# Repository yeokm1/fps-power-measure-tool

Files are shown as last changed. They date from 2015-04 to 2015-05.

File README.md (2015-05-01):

# fps-power-measure-tool
An Arduino setup to measure the frames per second (FPS) and power usage of a connected Android device. If you just want to measure the power usage, you can check out this [previous project](https://github.com/yeokm1/power_measure_tool) of mine. FPS data is obtained via ADB over the USB cable and power via a current sensor.

I created this tool for the purposes of my final year project (FYP) and I have open-sourced it in case anyone wishes to learn from this setup.

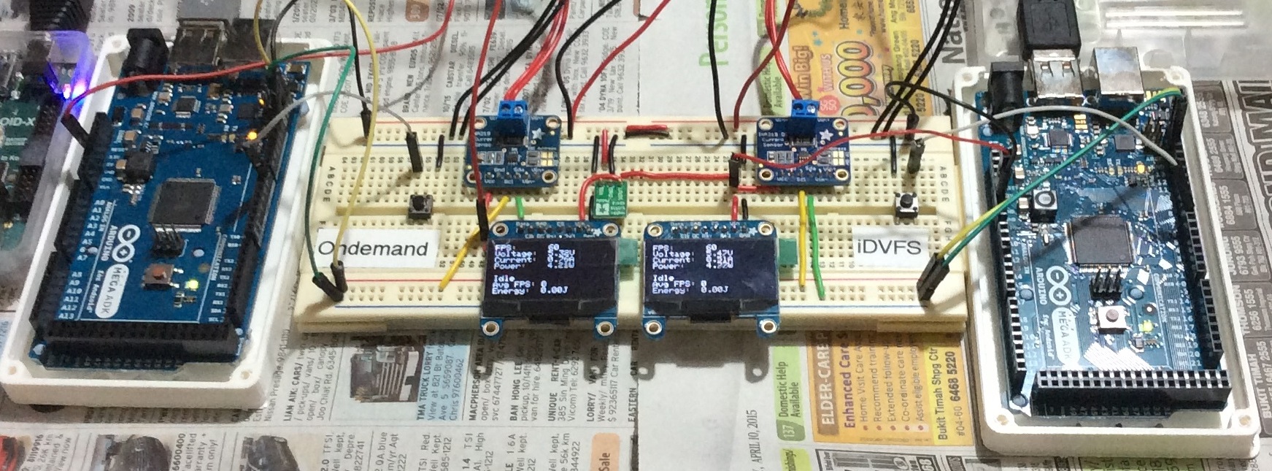
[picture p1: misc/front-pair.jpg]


Picture of two sets as used in my final year project.

###Video of my usage in my FYP
(https://www.youtube.com/watch?v=W7nGmd0tQ70)

###Schematic:

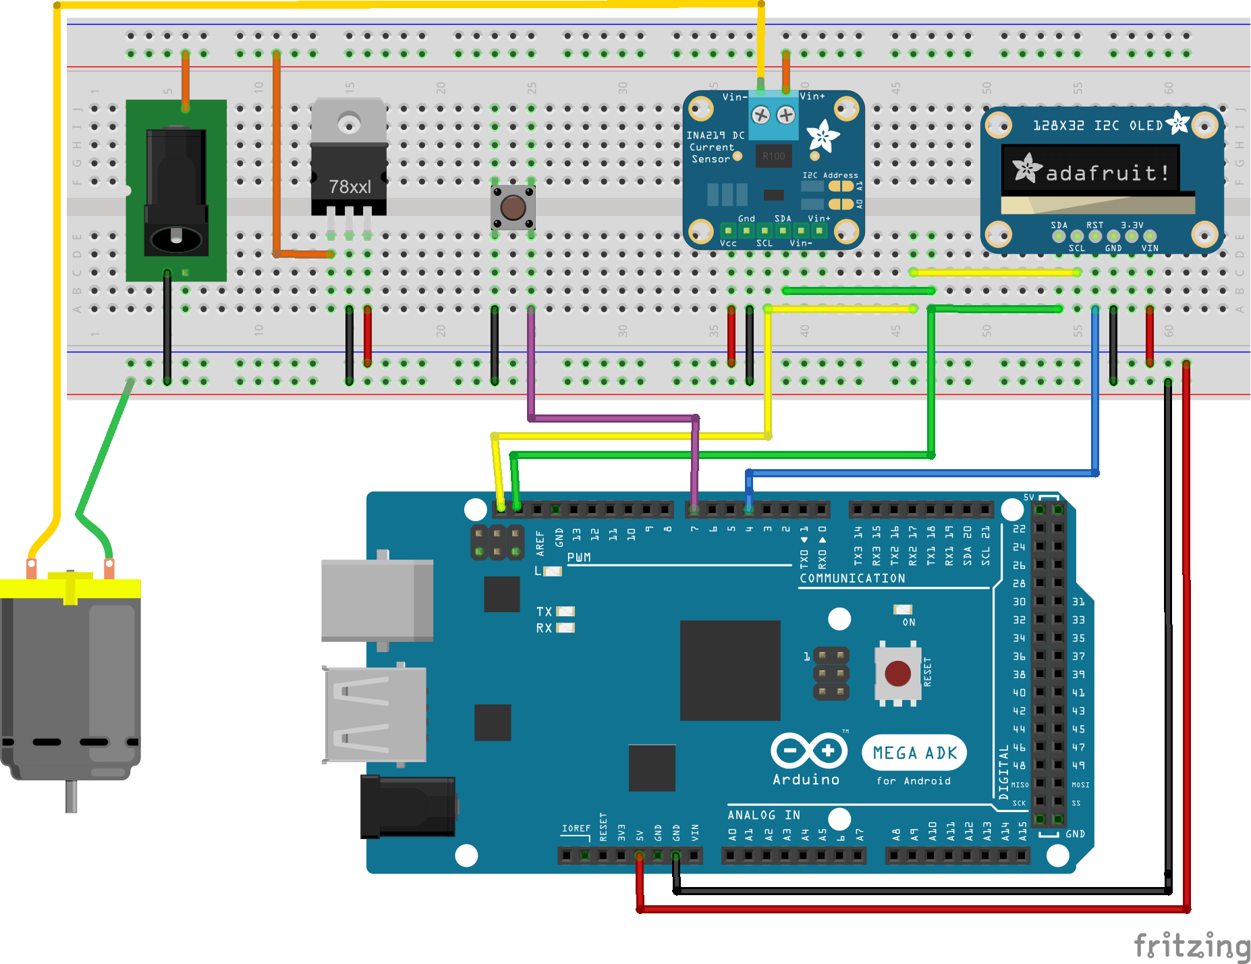
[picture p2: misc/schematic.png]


This logical schematic differs slightly from the physical curcuit layout. The motor here represents the phone. The barrel jack is the source supply power for both the motor and and the phone. The 78xxl represents any 5V voltage regulator you can use to supply 5V to the Arduino and the rest of the system in case your source voltage is very high.

##Parts List:
1. Arduino Mega ADK
2. Adafruit INA219 High Side DC Current Sensor Breakout
3. Adafruit 1.3" 128x64 OLED set to I2C
4. [Pololu 5V Step-Up/Step-Down Voltage Regulator S7V7F5](https://www.pololu.com/product/2119) (others will work fine)
5. Push Button

##References and libraries
1. [Smoothing algorithm](http://arduino.cc/en/Tutorial/Smoothing)
2. [Modified microbridge arduino](https://github.com/agoransson/microbridge-arduino)
3. [Standard C++ for Arduino](https://github.com/maniacbug/StandardCplusplus)

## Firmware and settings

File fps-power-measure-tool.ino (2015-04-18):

#include <Wire.h>
#include <SPI.h>
#include <Adb.h>
#include <StandardCplusplus.h>
#include <Stack>
#include <Adafruit_INA219.h>
#include <Adafruit_GFX.h>
#include <Adafruit_SSD1306.h>

using namespace std;

#define FPS_COMMAND "dumpsys SurfaceFlinger --latency SurfaceView && echo $\n"
#define FPS_RESULT_LINE_LENGTH 100
#define TIME_INTERVAL_FPS_SECOND 1000
#define TIME_SHELL_COMMAND_ISSUE 1000

#define MAX_FPS 60
#define NO_FPS_CALCULATED -1

#define POLL_RATE 500
#define SCREEN_RESET_PIN 4 //Digital 4
#define DISPLAY_CONTRAST true
#define PAST_POWER_TO_AVERAGE 10

#define MEASUREMENT_RATE 1000

#define PIN_BUTTON 7
#define DEBOUNCE_TIME 200

Adafruit_INA219 ina219;
Adafruit_SSD1306 display(SCREEN_RESET_PIN);

//Smoothing algorithm http://arduino.cc/en/Tutorial/Smoothing
float powerValues[PAST_POWER_TO_AVERAGE];      // the readings from the analog input
int powerValuesIndex = 0;                  // the index of the current reading
float powerValuesTotal = 0;                  // the running total
float powerValuesAverage = 0;                // the average

bool isMeasuring = false;

long lastPressedTime = millis();

double totalEnergyUsed = 0;
long totalFPSMeasured = 0;
int measurementsTaken = 0;
long timeLastMeasurementTaken = millis();

Connection * shell;

long shellLastCallTime = millis();

char resultLine[FPS_RESULT_LINE_LENGTH];
int currentLetter = 0;
stack<long> lastValues;
bool didPreviousFPSCommandSucceed = false;

int currentFPS = 0;

void setup() {
  Serial.begin(115200);
  ina219.begin();

  pinMode(PIN_BUTTON, INPUT_PULLUP);

  // Initialise the ADB subsystem.
  ADB::init();
  // Open an ADB stream to the phone's shell. Auto-reconnect
  shell = ADB::addConnection("shell:", true, adbEventHandler);

  // initialize with the OLED with I2C addr 0x3D (for the 128x64)
  display.begin(SSD1306_SWITCHCAPVCC, 0x3D);

  display.dim(DISPLAY_CONTRAST);

  display.clearDisplay();
  display.setTextColor(WHITE);
  display.setTextSize(1);
  display.setCursor(0, 0);
  display.display();

}

void loop() {
  float outputVolt = ina219.getBusVoltage_V();
  float outputAmp = ina219.getCurrent_mA() / 1000;

  float outputWattRaw = outputVolt * outputAmp;


  powerValuesTotal = powerValuesTotal - powerValues[powerValuesIndex];
  powerValues[powerValuesIndex] = outputWattRaw;
  powerValuesTotal = powerValuesTotal + powerValues[powerValuesIndex];
  powerValuesIndex++;

  // if we're at the end of the array...
  if (powerValuesIndex >= PAST_POWER_TO_AVERAGE) {
    powerValuesIndex = 0;
  }

  powerValuesAverage = powerValuesTotal / PAST_POWER_TO_AVERAGE;


  long currentTime = millis();
  // Poll the ADB subsystem.
  if (shell->status == ADB_OPEN) {


    if ((currentTime - shellLastCallTime) > TIME_SHELL_COMMAND_ISSUE) {
      shellLastCallTime = currentTime;
      ADB::writeString(shell, FPS_COMMAND);
    }
  }

  ADB::poll();


  int buttonStatus = digitalRead(PIN_BUTTON);

  if (buttonStatus == LOW && ((currentTime - lastPressedTime) > DEBOUNCE_TIME)) {
    lastPressedTime = currentTime;

    if (isMeasuring) {
      isMeasuring = false;
    } else {
      isMeasuring = true;

      measurementsTaken = 0;;
      totalEnergyUsed = 0;
      totalFPSMeasured = 0;
    }



  }



  if (isMeasuring) {
    if ((currentTime - timeLastMeasurementTaken) > MEASUREMENT_RATE) {

      if (currentFPS != NO_FPS_CALCULATED) {
        timeLastMeasurementTaken = currentTime;

        measurementsTaken++;
        totalEnergyUsed += powerValuesAverage;
        totalFPSMeasured += currentFPS;
      }

    }

  }



  display.clearDisplay();
  display.setCursor(0, 0);
  
  display.print("FPS:      ");
  display.println(currentFPS);

  display.print("Voltage:  ");
  display.print(outputVolt, 2);
  display.println("V");

  display.print("Current:  ");
  display.print(outputAmp, 2);
  display.println("A");

  display.print("Power:    ");
  display.print(powerValuesAverage, 2);
  display.println("W");


  display.println();

  int averageFPS = 0;

  if (measurementsTaken != 0) {
    averageFPS = totalFPSMeasured / measurementsTaken;
  }

  if (isMeasuring) {

    int mod750 = currentTime % 1500;

    if (mod750 < 750) {
      display.println("Measuring");
    } else {
      display.println("Measuring...");
    }

  } else {
    display.println("Idle");
  }

  display.print("Avg FPS: ");
  display.println(averageFPS);

  display.print("Energy:  ");
  display.print(totalEnergyUsed);
  display.println("J");




  display.display();

}

void adbEventHandler(Connection * connection, adb_eventType event, uint16_t length, uint8_t * data)
{
  if (event == ADB_CONNECTION_RECEIVE) {
    for (int i = 0; i < length; i++) {

      char recvData = data[i];

      if (recvData == '\n') {

        //End this line in the array
        resultLine[currentLetter] = '\0';
        currentLetter = 0;

        //Get to third number
        strtok(resultLine, "\t");
        strtok(NULL, "\t");
        char * finishFrameTime = strtok(NULL, "\t");

        if (finishFrameTime != NULL) {
          int frameStrLen = strlen(finishFrameTime);

          //Chop last 6 characters away to keep within 32bits so atol can work
          finishFrameTime[frameStrLen - 7] = '\0';
          long finishFrameTimeLn = atol(finishFrameTime);
          lastValues.push(finishFrameTimeLn);

        }


      } else if (recvData == '$') {
        //Reached end of command



        currentLetter = 0;

        if (lastValues.size() == 0) {

          if (didPreviousFPSCommandSucceed == false) {
            currentFPS = NO_FPS_CALCULATED;
          }

          didPreviousFPSCommandSucceed = false;
          return;
        }

        currentFPS = framesCounted();
        didPreviousFPSCommandSucceed = true;

      } else {
        resultLine[currentLetter] = recvData;
        currentLetter++;
      }


    }

  }


}

int framesCounted() {
  int frameCount = 0;
  long lastFrameFinishedTime = lastValues.top();


  while (!lastValues.empty()) {
    long currentValue = lastValues.top();
    lastValues.pop();

    if ((lastFrameFinishedTime - currentValue) <= TIME_INTERVAL_FPS_SECOND) {
      frameCount++;
    }
  }


  if (frameCount > MAX_FPS) {
    frameCount = MAX_FPS;
  } else if (frameCount < 2) {
    frameCount = NO_FPS_CALCULATED;
  }

  return frameCount;

}

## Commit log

2015-04-18 set initial fps to 0 to allow recording of power if no FPS obtained
2015-05-01 schematic and picture
    [schematic.fzz]
2015-05-01 missing scl wire
    [schematic.fzz]
2015-05-02 get last frame value after pop
